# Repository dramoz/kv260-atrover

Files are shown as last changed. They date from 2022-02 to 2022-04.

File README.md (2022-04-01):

# Kria KV260-ATRover
[Adaptive Computing Challenge 2021 report](https://github.com/dramoz/kv260-atrover/blob/main/KV260-atrover.md)

# License(s)

***Copyright (c) 2022 Danilo Ramos***

- Code is licensed under MIT License unless specified to the contrary on the file or subfolder.

- 3D models are licensed under [Attribution-ShareAlike 4.0 International (CC BY-SA 4.0)](https://creativecommons.org/licenses/by-sa/4.0/) unless specified to the contrary on the file(s) or subfolder(s).

- Most models are licensed under [Attribution-NonCommercial-ShareAlike 4.0 International (CC BY-NC-SA 4.0)](https://creativecommons.org/licenses/by-nc-sa/4.0/), **unless specified in the file(s), subfolder(s) or website (please double check)**
  - [3Dmodels/modules/ModulesInfo.md](3Dmodels/modules/ModulesInfo.md)

THE FILES IN THIS REPOSITORY ARE PROVIDED BY THE COPYRIGHT HOLDERS AND CONTRIBUTORS "AS IS" AND ANY EXPRESS OR IMPLIED WARRANTIES, INCLUDING, BUT NOT LIMITED TO, THE IMPLIED WARRANTIES OF MERCHANTABILITY AND FITNESS FOR A PARTICULAR PURPOSE ARE DISCLAIMED. IN NO EVENT SHALL THE COPYRIGHT HOLDER OR CONTRIBUTORS BE LIABLE FOR ANY DIRECT, INDIRECT, INCIDENTAL, SPECIAL, EXEMPLARY, OR CONSEQUENTIAL DAMAGES (INCLUDING, BUT NOT LIMITED TO, PROCUREMENT OF SUBSTITUTE GOODS OR SERVICES; LOSS OF USE, DATA, OR PROFITS; OR BUSINESS INTERRUPTION) HOWEVER CAUSED AND ON ANY THEORY OF LIABILITY, WHETHER IN CONTRACT, STRICT LIABILITY, OR TORT (INCLUDING NEGLIGENCE OR OTHERWISE) ARISING IN ANY WAY OUT OF THE USE OF THIS SOFTWARE, EVEN IF ADVISED OF THE POSSIBILITY OF SUCH DAMAGE.

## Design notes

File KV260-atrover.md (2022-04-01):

# Kria KV260-ATROVER (mini)

***A journey through machine learning and Xilinx Kria KV260 Vision AI Starter Kit***

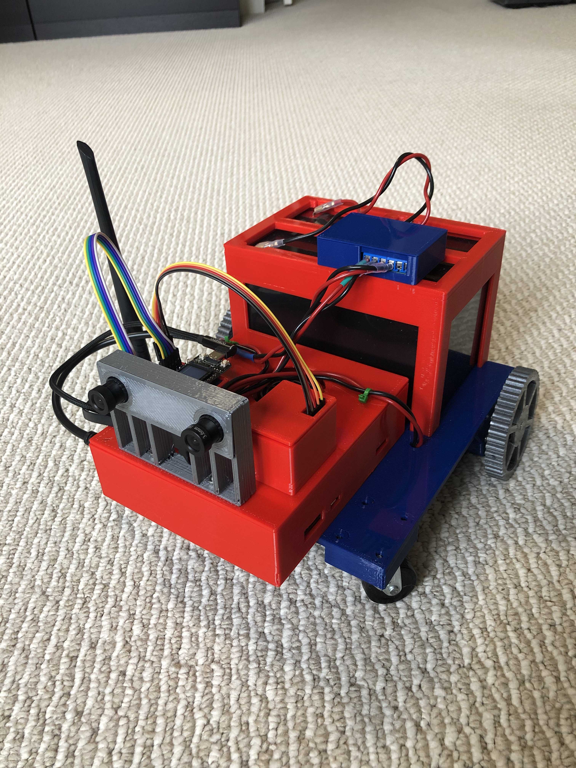
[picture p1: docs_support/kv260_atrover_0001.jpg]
|  |
| :----------------------------------------------------------: |

*Disclaimer:* The following project was done for the [Adaptive Computing Challenge 2021](https://www.hackster.io/contests/xilinxadaptivecomputing2021). Most of the code and 3D models are under [The MIT License | Open Source Initiative](https://opensource.org/licenses/MIT) or  [Attribution-ShareAlike 4.0 International (CC BY-SA 4.0)](https://creativecommons.org/licenses/by-sa/4.0/) unless specified to the contrary. A copy of this document and the corresponding project files are located at the [KV260-ATRover GitHub repository](https://github.com/dramoz/kv260-atrover). As part of the application process, I received a [free Kria KV260 AI Starter Kit + Basic Accessory Pack](https://www.hackster.io/contests/xilinxadaptivecomputing2021/hardware_applications#challengeNav).

⚠ This project uses high DC amperage which can be ☠ -  please use extreme caution.

⚠ All links and references are set to match the tools version used in this project, which most of the time are not the latest. Readers are welcome to go further, as new releases came with significant improvements.

> Vitis-AI v1.4 and v1.4.1 share the same database, and I found that the information available is more complete on v1.4.1

# Introduction

The idea of having a self-driving vehicle platform has been going around my head for a long time now. First, it started with my personal experience with some robot vacuums which became a relation of love and not-that-much hate. With the passing of the years, I have enjoyed the benefits of keeping my floors clean (I suffer a lot from dust allergies), but with the passing of the years, I keep seeing the same problems - which became worst when your family grows and your kids behave like kids.

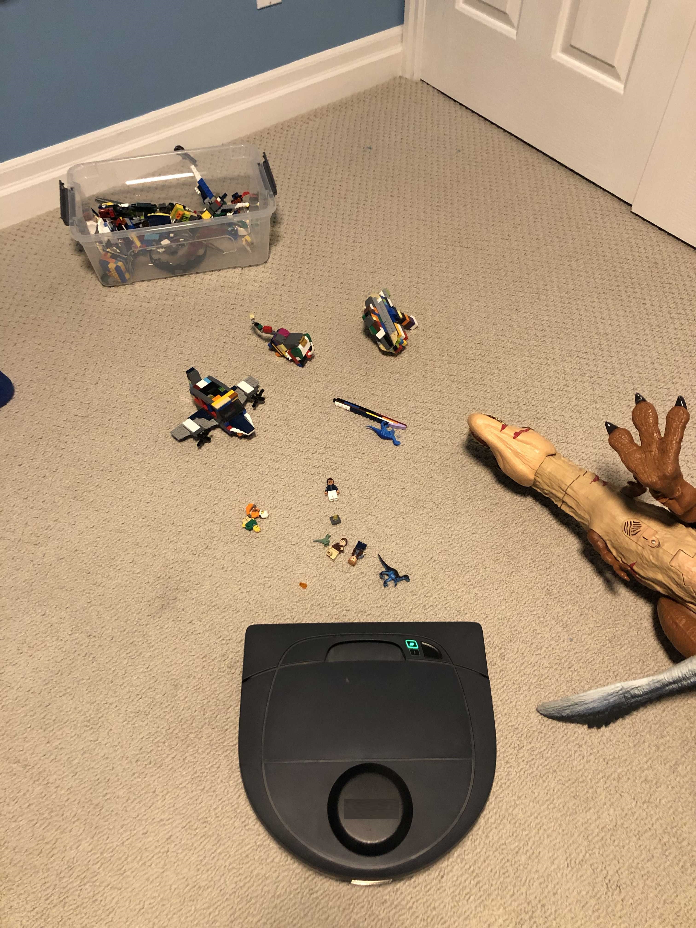
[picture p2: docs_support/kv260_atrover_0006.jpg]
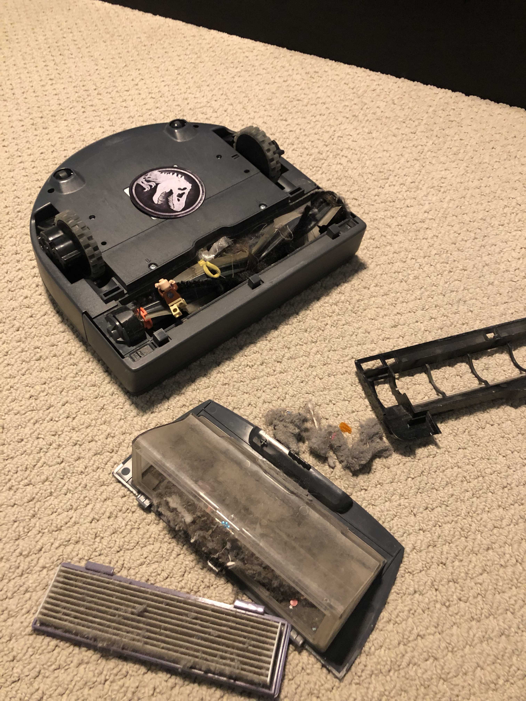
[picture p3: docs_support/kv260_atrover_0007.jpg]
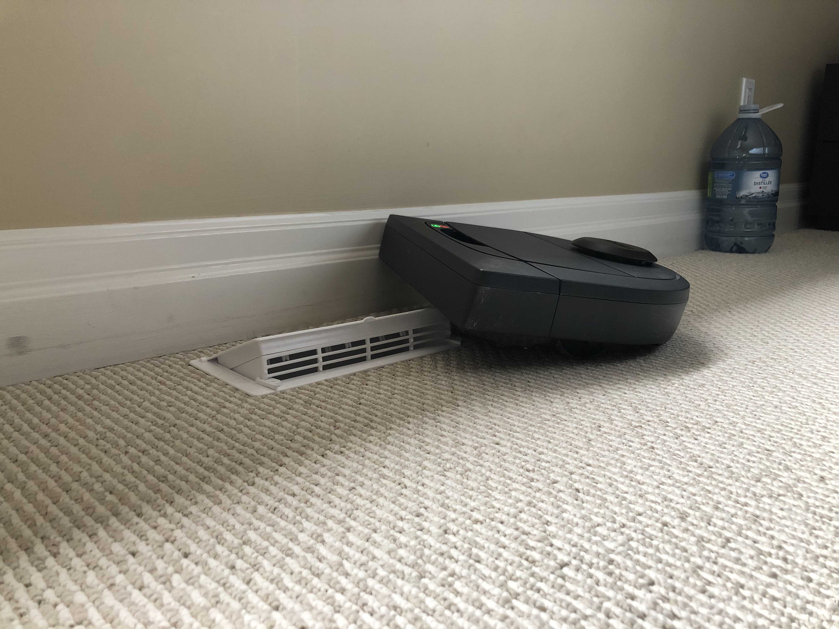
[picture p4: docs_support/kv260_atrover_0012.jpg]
|  |  |  |
| --- | --- | --- |

And then the we moved to a rural house outside Ottawa, and cutting the grass although relaxing, is time-consuming. I started working around a full autonomous acreage lawn mower which I wanted to have an FPGA (just because), when I came across the [Adaptive Computing Challenge 2021](https://www.hackster.io/contests/xilinxadaptivecomputing2021) on [HacksterIO](https://www.hackster.io/) - and that was my [application for free hardware](https://www.hackster.io/contests/xilinxadaptivecomputing2021/hardware_applications/13951). But after starting from almost zero knowledge on both Xilinx Zynq Ultrascale+ and AI/ML (Artificial Intelligence/Machine Learning) I run out of time, plus I live in Canada, so a lawnmower was out of the question during winter.

So I decided to step back, and start with a basic ATRover (AuTonomous Rover) and the KRIA KV260-ATRover  mini version was born - the prototype of an autonomous self-driving mini-rover based on the [Kria KV260 Vision AI Starter Kit](https://www.xilinx.com/products/som/kria/kv260-vision-starter-kit.html) (Zynq Ultrascale+)

My objectives when joining the challenge were:

- Learn about the Xilinx Zynq Ultrascale+ devices
- Go into AI (Artificial Intelligence) and ML (Machine Learning)

## KV260-ATROVER (mini)

The KV260-ATROVER (mini) has the following features:

- Full 3D Printed chassis with OpenSCAD
- KRIA KV260 board (master)
  - AI Object Identification (YOLOv4)
  - OpenCV Stereo Vision for distance estimation (reference)

- TTGO-T1 board (slave)
  - Dual DC motor control

## Motivation

Stereo Vision, DC motor control, route planning, and navigation require a lot of calibration. In the long term, my final goal is to explore and implement a fully autonomous robot with self-learning capabilities, where the required effort for initial calibration is minimized.

As an example, you can watch [OpenCV Python ](https://www.youtube.com/playlist?list=PLLf0llgjmNiZrt5QocH1zq7ih-GdKMgCY)videos from [Clayton Darwin ](https://www.youtube.com/c/ClaytonDarwin)where he does a good explanation of the required process to do triangulation using two cameras and OpenCV. An that is just triangulation, PID motor control, route planning, and context awareness by themself are quite complex, doable but limited, and space-constrained - and this is why and where AI/ML (CNN) keeps growing in many fields.

# Hardware

The ATRover chassis is a custom-made 3D printed model. The design was done in [OpenSCAD](https://openscad.org/). The chassis is modular, so it is possible to reuse for example the KV260 enclosure for future projects. The weight of the assembled ATRover is around 6Kg.

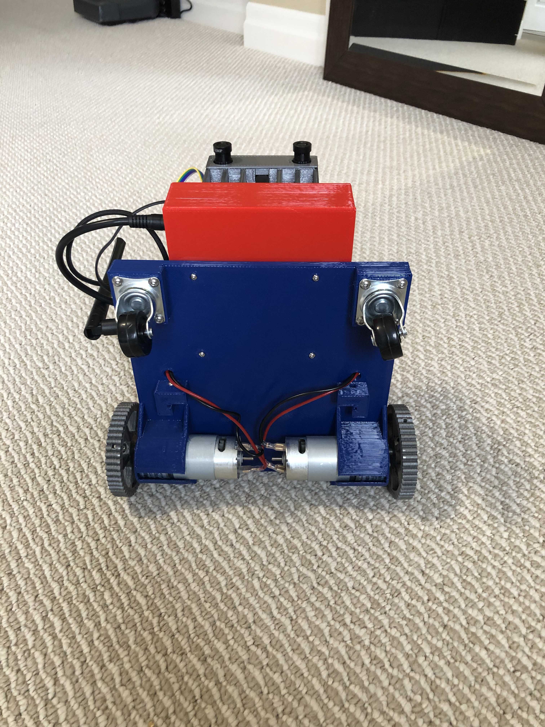
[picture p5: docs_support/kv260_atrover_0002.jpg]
|  |  |
| --- | --- |
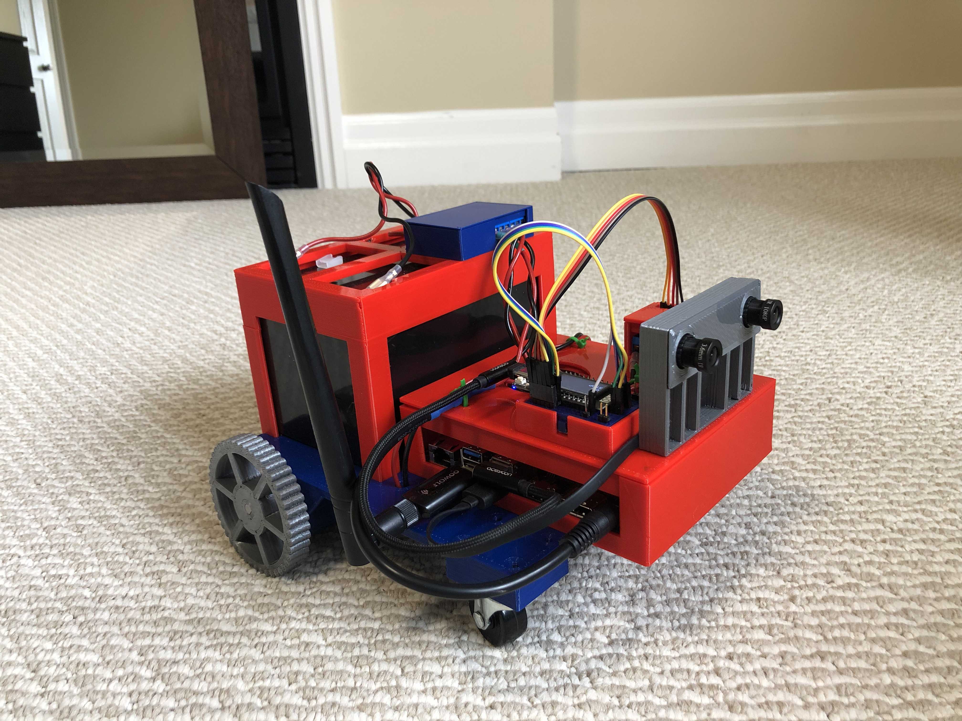
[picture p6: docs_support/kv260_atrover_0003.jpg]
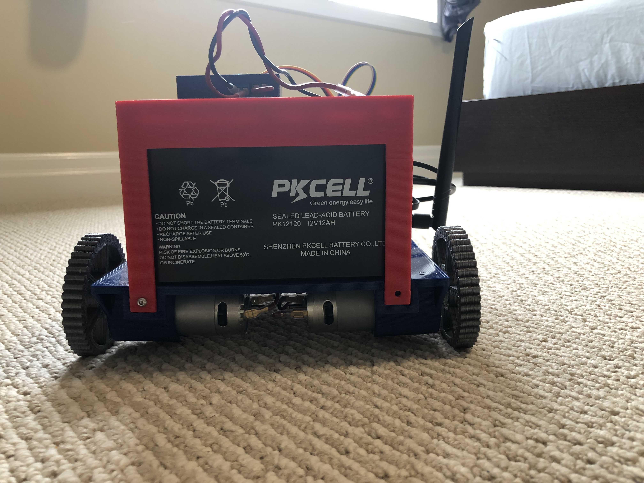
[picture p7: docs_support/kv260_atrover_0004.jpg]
|  |  |

## [Kria KV260 Vision AI Starter Kit](https://www.xilinx.com/products/som/kria/kv260-vision-starter-kit.html)

The hardware selected for this project is the Xilinx KRIA KV260 board, which was awarded as free hardware in this challenge. Another good candidate is the [Avnet - Ultra96-V2 Board](https://www.avnet.com/wps/portal/us/products/new-product-introductions/npi/aes-ultra96-v2/) which has similar characteristics. One advantage of the KRIA Zynq (XCK26) vs the ZU3EG in the Ultra96-V2 is the [VCU (Video Codec Unit)](https://www.xilinx.com/products/intellectual-property/v-vcu.html) which makes it an ideal platform for R&D video applications (live stream)

The KRIA SOM installed in the KV260 Vision AI Starter Kit is a special (non-commercial) SOM, with similar characteristics to the [Kria K26C SOM](https://www.xilinx.com/products/som/kria/k26c-commercial.html). The KV260 has only a single 240-Pin connector and is not certified.

## Stereo Camera

For this project, the [HBVCAM-1780-2](https://www.hbvcamera.com/dual-lens-usb-cameras/1mp-720p-hd-binocular-camera-module.html) binocular camera was selected as it already outputs a dual stereo image synchronized in a single USB port (stream), and it has a decent price.

The camera was tested with https://webcamtests.com/ to validate the manufacturer parameters:

- Max. resolution: 1.84 MP, 30 FPS at 2560×720 (dual image, 2x 1280x720)
- Angle of view: 72 degrees (3.6mm lenses)
- Distance between lenses: 60mm
- Object distance: 30cm ~ $\infty$ (fixed focus - manual adjustable)
- Dual Image Resolution: `640*240 (30fps), 1280*480 (30fps), 2560*720 (25fps)` (validated)
  - single camera: `320*240 (30fps), 640*480(30fps), 1280*720 (30fps)`
- Connection: micro USB2.0
- 2x[OV9732](https://www.ovt.com/products/ov09732-h35a/) Sensors
  - Optical format: 1/4"
  - Array size: 1280*720

| 1MP 720P HD Binocular Camera Module |
| :----------------------------------------------------------: |

As the camera lenses produce some distortion on the capture images, it is necessary to perform a camera calibration as described in [Stereo Vision Camera Calibration in Python with OpenCV](https://youtu.be/yKypaVl6qQo). A modified set of Python scripts used for this project can be found at https://github.com/dramoz/kv260-atrover/tree/main/scripts/camera_calibration_data_gen. The parameters obtained are particular for the module used in this project, and it must be done on a per-module basis.

The scripts are based on [niconielsen32-ComputerVision/stereoVisionCalibration](https://github.com/niconielsen32/ComputerVision/tree/master/stereoVisionCalibration) modified to use one single stereo camera stream plus some personal modifications.

## DC Motors

For the KV260-ATRover the [CHIHAI GM37-550 DC motor ](https://www.aliexpress.com/item/4000808942638.html?pdp_ext_f={"sku_id":"10000008104483462","ship_from":""}&gps-id=pcStoreJustForYou&scm=1007.23125.137358.0&scm_id=1007.23125.137358.0&scm-url=1007.23125.137358.0&pvid=49f50fc1-c29b-4a45-91ae-5cb7468be7b7&spm=a2g0o.store_pc_home.smartJustForYou_718209649.0)with a gear ratio of 50:1 and 12Vdc with a maximum input power of 40W was selected.

> The current DC motors are too powerful for the KV260-ATRover mini. They were selected initially for the lawnmower which has a bigger heavier chassis (higher torque requirement) and larger wheels (reducing the speed of the ATRover and therefore increasing the minimum required PWM duty cycle)

|  |
| :----------------------------------------------------------: |

### DC Motor Driver(s)

For the motor drivers, the [ZK-5AD](https://www.aliexpress.com/item/1005002100401855.html) board was selected. It has two [TA6586](https://www.micros.com.pl/mediaserver/UITA6586_0001.pdf) monolithic IC for driving bi-directional DC motors.

- Working Voltage: DC 3.0V-14V
- Input Signal Voltage: DC 2.2V-6.0V
- Drive Current: 5A
- Standby Current: 10uA
- Working Temperature:-20 to 85 Celsius

| ZK-5AD L298N5A Dual DC Motor Drive Module (1 piece) ⋆ | ZK-5AD L298N5A Dual DC Motor Drive Module (1 piece) |
| :---: | --- |

## [LILYGO® TTGO T-Display ESP32](http://www.lilygo.cn/prod_view.aspx?TypeId=50062&Id=1400&FId=t3:50062:3)

For the DC motor control, the plan was to use the Zynq+ Dual-Core ARM  Cortex-R5 processors with FreeRTOS. The initial test was done with a TTGO T-Display (aka TTGO-T1) board. Although I was planning to use the [PMOD](https://digilent.com/reference/pmod/start) to generate the required PWM signals, after burning two drivers and one TTGO-T1 board I decided to leave it for another day.

You can buy a TTGO-T1 board at [Aliexpress](https://www.aliexpress.com/item/33048962331.html) (the Official [LILYGO store](https://lilygo.he.aliexpress.com/store/2090076?spm=a2g0o.detail.1000061.1.59f8142fz8JkSi)). It is based on the [ESP32 Espresiff](https://www.espressif.com/en/products/socs/esp32) ([Wikipedia](https://en.wikipedia.org/wiki/ESP32])), a 32bit MCU Tensilica Xtensa LX6 with integrated WiFi, Bluetooth, and a lot of peripherals. This is the board I usually use for R&D.

| LILYGO® TTGO T-Display ESP32 WiFi and Bluetooth Module Development Board For Arduino 1.14 Inch LCD |
| ------------------------------------------------------------ |

## USB WiFi dongle

To do some telemetry and get some real-time feedback when testing the system, wireless communication with good throughput and low latency was required. As the KV260 lacks a dedicated wireless communication interface, a USB WiFi dongle was selected for this. For more detailed information on how to install the drivers and set up the device used in this project please refer to [Adding USB-WiFi for the Kria KV260 (Ubuntu 20.04.3).](https://www.hackster.io/dramoz/adding-usb-wifi-for-the-kria-kv260-ubuntu-20-04-3-b5e8ea)

|  |
| :----------------------------------------------------------: |

## Power considerations

As the ATRover is a mobile platform, an appropriate power supply was required. SLA batteries are widely used in robotic applications. A [SLA12V/12Ah](https://www.power-sonic.com/wp-content/uploads/2018/12/Technical-Manual.pdf) battery was selected given the following rough estimates:

- KV-260 power requirements: 36W (4Ah)
- DC Motors: 2x21W (42W, 3.5Ah)

Roughly at full power, the ATRover would require 80W or 6.7Ah. Note that the 12Ah capacity is rated for a 20Hr operation. A constant 3~4A discharge would reduce the capacity to ~9Ah, and give you between 2~3hr. The motors are running at half the capacity or lower speed.

## Other components

To complete assemble an ATRover mini, some other components are required:

- 3D printed chassis
- M3 screws
  - chasis
- Power distribution block
- Power cables ([AWG16](https://www.powerstream.com/Wire_Size.htm))
  - KRIA power cable
  - DC motors
- TTGO-T1 ZK-5AD connector
- micro-USB cable for Stereo Camera
- USB-C cable for TTGO-T1

Please refer to the BOM at the repository for more information.

# Software/Firmware

The journey through the KRIA KV-260 and Xilinx Development Tools was extensive and extenuating. Although I have learned a lot, in the end, with the timeline nearer every day, I have to make a choice and start doing some real deployment.

Given that there was no easy way to install the USB/WiFi drivers or any other driver (like the TTGO-T1 USB-Serial) in the [Petalinux ](https://www.xilinx.com/products/design-tools/embedded-software/petalinux-sdk.htm)flow, I decided to work with Ubuntu. [PYNQ for the KV260 ](https://github.com/Xilinx/Kria-PYNQ)was made available [two months ago.](https://community.element14.com/technologies/fpga-group/f/forum/50595/pynq-now-available-for-the-kria-kv260-vision-ai-starter-kit) Given that scripting is clearer with Python, I decided to switch to PYNQ. Initially, it worked right away without any issues. Running the examples and tutorials is more comfortable and easier to grasp.

## Required tools

- [Kria-PYNQ](https://github.com/Xilinx/Kria-PYNQ)
- [Vitis-AI v1.4.1](https://github.com/Xilinx/Vitis-AI/tree/1.4.1): the DPU-PYNQ uses version 1.4, but using v1.4.1
-  [Visual Code](https://code.visualstudio.com/) + [PlatformIO](https://platformio.org/platformio-ide): the KV260 ATRover uses a TTGO-T1 board to control the DC motors via USB/Serial port. Please follow the instructions on each website to install the tools.

## [Kria PYNQ](https://github.com/Xilinx/Kria-PYNQ)

> [Kria SOMs x Ubuntu x PYNQ](https://pages.xilinx.com/EN-WB-2022-03-22-KriaPYNQUbuntu_LP-Registration.html): nice introductory webinar

The PYNQ framework on the KRIA KV-260 is pretty simple to use.

- It runs on Ubuntu 20.04.04 LTS
  - Easier to install new drivers or tools for development (e.g. USB WiFi dongle, USB/UART drivers)
  - Visual Code SSH + PlatformIO Remote Development
- Faster to test and deploy new ideas
  - Python + Jupyter-lab
  - DPU ready overlay (B4096)
- Easy to install and error prune
- Remote access with remote graphics applications (`ssh -X` )

But there are some "*drawbacks*":

- Cannot load multiple overlays
  - e.g. if you need the DPU but at the same time some video pre-processing you are out of luck, but of course you can develop your own overlays
- Performance: in theory, as you are running over Python you will suffer from latency and throughput. 
  - I have not test it, but I will do in the future. Nevertheless, for R&D and testing it is good enough.

### PYNQ install

> At the moment, PYNQ - KRIA installation is *"broken"* [Unable to install PYNQ #9](https://github.com/Xilinx/Kria-PYNQ/issues/9)
> **It is possible to get PYNQ with Xilinx Dev. working by skipping the initial:**
>
>    `sudo apt update; sudo apt upgrade`
>
> and do it only at the end!
>
> *Currently Canonical and PYNQ are working on a new release that will address this issue.*

To install, just follow the instructions on the official GitHub repository https://github.com/Xilinx/Kria-PYNQ, which can be summarized as:

- Download the [Ubuntu Desktop 20.04.4 LTS for Xilinx Kria KV260](https://ubuntu.com/download/xilinx) ([direct download link](https://people.canonical.com/~platform/images/xilinx/kria/iot-kria-classic-desktop-2004-x03-20211110-98.img.xz))

- Burn the image on an SD card

  - Load the SC card and power up the board

- Logging (GUI or Terminal, GUI experience is recommended)

  - **username**: ubuntu

  - **password**: ubuntu (OS will prompt to set a new password)

    after the first password input, key the current password again - **ubuntu** and enter a new password (twice)

  - Skip Ubuntu/GNOME settings (I did not see a need to do a full Ubuntu configuration at the moment)
  - Optional Settings (GUI: right click)
    - Appearance: move and resize the toolbar
    - Power.Blank_Screen: Never

> After initial configuration and having a valid IP, I prefer to do most of the configuration using ssh
>
> `ssh ubuntu@xxx.xxx.xxx.xxx`

- On a terminal window

  ```bash
  # Setup git credentials
  git config --global user.email "yout@email"
  git config --global user.name "Your Name"
  ```

  > **Skip next step until new Ubuntu/PYNQ release**

  ```bash
  sudo apt update -y; sudo apt upgrade -y; sudo apt autoremove -y;
  sudo reboot
  ```

> Note: As soon as you power up the KRIA KV260, after login - the OS will start an update status query, which will lock some process causing the next steps to lock for a couple of minutes.
>
> Some info related to this issue can be read here https://xilinx-wiki.atlassian.net/wiki/spaces/A/pages/2037317633/Getting+Started+with+Certified+Ubuntu+20.04+LTS+for+Xilinx+Devices

| SOM Kria KV260 connection animation |
| :----------------------------------------------------------: |

> The IAS camera module is not required!!!

- Setup Xilinx Development Environment

  ```bash
  # if GUI, open a new terminal session (right click)
  cd ~
  sudo snap install xlnx-config --classic
  xlnx-config.sysinit
  # -> [Y] when asked
  ```

- Install PYNQ

  ```bash
  git clone https://github.com/Xilinx/Kria-PYNQ.git
  cd Kria-PYNQ/
  sudo bash install.sh
  ```

- Testing PYNQ
  - Run the [DPU resnet50](http://kria:9090/lab/workspaces/auto-e/tree/pynq-dpu/dpu_resnet50.ipynb) to validate the DPU-PYNQ installation

```bash
# Open in your local desktop webbrowser:
kria:9090/lab
# !try some examples
# if the kria:9090/lab is not working, try the IP directly
# To get the IP type the `ip a` command and look for eth0:...
ip a
```

> 3: eth0: <BROADCAST,MULTICAST,UP,LOWER_UP> mtu 1500 qdisc mq state UP group default qlen 1000
>     link/ether 00:0a:35:00:22:01 brd ff:ff:ff:ff:ff:ff
>     inet **192.168.0.134**/24 brd 192.168.0.255 scope global dynamic noprefixroute eth0
>        valid_lft 7191sec preferred_lft 7191sec
>     inet6 fe80::1fe:9c9e:1eaf:a932/64 scope link noprefixroute 
>        valid_lft forever preferred_lft forever

## Vitis-AI (v1.4.1)

> Vitis-AI requires around 100GB of hard drive space

As the current Vitis-AI version is 2.0, but DPU-PYNQ requires v1.4.1, please follow the next steps to install the proper tool version. Vitis-AI is installed and run in your local machine (Ubuntu)

**Installation steps**

- [Install docker](https://docs.docker.com/engine/install/)

  ```bash
  # Prerequisites
  sudo apt install -y ca-certificates curl gnupg lsb-release
  curl -fsSL https://download.docker.com/linux/ubuntu/gpg | sudo gpg --dearmor -o /usr/share/keyrings/docker-archive-keyring.gpg
  echo "deb [arch=$(dpkg --print-architecture) signed-by=/usr/share/keyrings/docker-archive-keyring.gpg] https://download.docker.com/linux/ubuntu $(lsb_release -cs) stable" | sudo tee /etc/apt/sources.list.d/docker.list > /dev/null
  
  # Docker engine
  sudo apt install -y docker-ce docker-ce-cli containerd.io
  
  # Setup group access
  sudo groupadd docker
  sudo usermod -aG docker $USER
  su $USER
  
  # Test installation
  sudo docker run hello-world
  ```

- Install Vitis-AI

  ```bash
  mkdir -p ~/repos
  cd repos
  git clone --recurse-submodules https://github.com/Xilinx/Vitis-AI
  cd Vitis-AI
  git checkout 1.4
  ```

- Get [Docker image](https://github.com/Xilinx/Vitis-AI/blob/1.4/docs/quick-start/install/install_docker/load_run_docker.md):

  ```bash
  docker pull xilinx/vitis-ai-cpu:1.4.916
  ```

  Alternatively, you can build the docker image with:

  ```bash
  cd setup/docker
  ./docker_build_cpu.sh
  ```

- Launch Vitis-AI

  ```bash
  ./docker_run.sh xilinx/vitis-ai-cpu:1.4.916
  ```

## Additional Drivers & Ubuntu configuration

### Ubuntu packages

```bash
sudo apt install -y dkms net-tools build-essential
```

### USB WiFi

```bash
mkdir repos; cd repos
git clone https://github.com/morrownr/88x2bu-20210702
cd 88x2bu-20210702
sudo ARCH=arm64 ./install-driver.sh
```

> Do you want to edit the driver options file now? [y/N] **n**
> Do you want to reboot now? (recommended) [y/N] **n**

```bash
# TTGO-T1 UART/USB drivers
cd ~/repos
git clone https://github.com/WCHSoftGroup/ch343ser_linux.git
cd ch343ser_linux/driver
make ARCH=arm64
sudo make install
sudo reboot
```

### WiFi configuration

The easiest way to configure the WiFi is through GNOME. After login, click on the down icon near the power button ⏻▼ and select your network. This connection will be preserved after shutdown without the need of login.

Alternatively you can set it on the command line. Currently I do not know how to make a connection permanently (aka WiFi connection without login), so the GUI method is recommended.

### Final steps

```bash
sudo apt update -y; sudo apt upgrade -y; sudo apt autoremove -y; sudo reboot
```

### ***Optional packages***

```bash
sudo apt install -y graphviz gtkwave tree meld
```

### Optional Python Virtualenv Wrapper

> ⚠ PYNQ has its own `virtualenv` setup, I did not test creating a new one and I do not know if there would be any side effect on doing so

```bash
cd ~
pip3 install virtualenv virtualenvwrapper
```

With your favorite editor append the following lines to `.bashrc`

> \# virtualenv and virtualenvwrapper
> export WORKON_HOME=\${HOME}/.virtualenvs
> export VIRTUALENVWRAPPER_PYTHON=/usr/bin/python3
> export VIRTUALENVWRAPPER_VIRTUALENV=\$HOME/.local/bin/virtualenv
> source \$HOME/.local/bin/virtualenvwrapper.sh

💡In the [KV260-ATRover GitHub repository](https://github.com/dramoz/kv260-atrover) I have provided a set of `.bash` configuration scripts that include some extra setup for Ubuntu command line terminals including the above `virtualenv and virtualwrapper` setup. 

They will transform the command line prompt from

|  |
| ------------------------------------------------------------ |

to

|  |
| :----------------------------------------------------------- |

You can install them next after cloning the project repository.

# Project files

```bash
cd ~
mkdir dev
cd dev
git clone https://github.com/dramoz/kv260-atrover
```

NOTE: you can use [Visual Code remotely with SSH](https://code.visualstudio.com/docs/remote/ssh).

> Click ≶ icon on the bottom left corner and create a new connection.

Create a symbolic link to the repository so it is accessible from jupyter-lab

```bash
cd $PYNQ_JUPYTER_NOTEBOOKS
ln -s $HOME/dev/kv260-atrover/ kv260-atrover
```

Copy the `.bashrc` configuration (optional)

```bash
cp -fv ~/dev/kv260-atrover/scripts/.bash* ~/
source ~/.bashrc
```

Finally, install the required python dependencies:

```bash
pip install -r ~/dev/kv260-atrover/scripts/requirements.txt
```

### TTGO-T1 firmware

The TTGO-T1 code is a simple four-channel PWM generator connected to the ZK-5AD motor driver. It communicates to the KV260 board with a USB/Serial port. The KV260 application send the following commands as requried:

- `*m###, m in [f, b, r, l, s]`

  - f: forward
  - b: backward
  - r: turn right
  - l: turn left
  - s: stop
  - ###: desired step value, between `min/max_step` range (number string must be 3 numeric characters)

  example: `*f064`

- `!xxxx`: emergency stop (any four *xxxx* characters)

The following parameters can be configured (required to flash a new firmware into the board):

- `min/max speed`: in steps to control the PWM duty cycle
- `PWM frequency` and `PWM resolution`
- acceleration: by means of `speed_step` and update rate (`accel_step_ms`)

The default parameters were set on a trial an error basis as:

- `min_step`: 32, `max_step`: 128
- [PWM frequency](https://electronics.stackexchange.com/questions/242293/is-there-an-ideal-pwm-frequency-for-dc-brush-motors/): 8Hz
- `speed_step`: 8, `accel_step_ms`: 200

The firmware of the TTGO-T1 board was developed using Visual Code PlatformIO. After installing Visual Code + PlatformIO, clone the project repository on a local machine and add the [ttgo-atrover-motor-control](https://github.com/dramoz/kv260-atrover/tree/main/ttgo-atrover-motor_control) project to PlatformIO. Connect the board to an available USB serial port, compile (✓) and flash (➔) the board by clicking on the icons located at the bottom toolbar in VS code.

💡It is possible to program the TTGO-T1 board directly from the KRIA KV-260 with [PlatformIO Remote Development](https://docs.platformio.org/en/stable/plus/pio-remote.html) tools.

> A free PlatformIO account is required for remote development.

On your local machine

- Open Visual Studio Code

  ```bash
  # CTRL+SHIFT+P
  # Start typing Platf...
  # -> Click PlatformIO: New Terminal
  pio account register
  pio account login
  ```

On the KV260

- Install

  ```bash
  python3 -c "$(curl -fsSL https://raw.githubusercontent.com/platformio/platformio/master/scripts/get-platformio.py)"
  ```

- Update `.bashrc` (already present if `.bashrc` was updated from the repository)

  ```bash
  export PATH=$PATH:$HOME/.platformio/penv/bin
  ```

- Install the [platformio-udev-rules](https://docs.platformio.org/en/stable/faq.html#platformio-udev-rules)

  ```bash
  curl -fsSL https://raw.githubusercontent.com/platformio/platformio-core/master/scripts/99-platformio-udev.rules | sudo tee /etc/udev/rules.d/99-platformio-udev.rules
  sudo service udev restart
  sudo usermod -a -G dialout $USER
  sudo usermod -a -G plugdev $USER
  ```

- Login and start the remote agent

  ```bash
  pio account login
  pio remote agent start
  ```

  > The first call to `pio remote agent start` will require some time while the required packages and dependencies are installed

Local machine remote programming

- On a PlatformIO terminal in VS code

  > Check that the terminal current path is at `~/dev/kv260-atrover/ttgo-atrover-motor_control/`

- Check KV260 remote agent

  ```bash
  #pio account login (if required)
  pio remote agent list
  ```

  > kria
  > \----
  > ID: 827c99104301d4120ea475faee3371703eddc89f
  > Started: 2022-03-27 00:28:45

  ```bash
  pio remote run -t upload --upload-port /dev/ttyCH343USB0
  ```

PlatformIO Remote Development is a useful remote programing tool, as if required for example to change the PWM frequency for the DC motors control, we can reprogram the TTGO-T1 without the need of unplugging it from the KV260 board.

# Basic system tests

All the scripts are done in Python using Visual Studio code. Although JupyterLab was nice for the initial R&D, it is faster to run some OpenCV like `imshow()` outside the Jupyter environment, with `ssh -X`.

## TTGO-T1 and DC motors

```bash
ssh ubuntu@kria_ip
screen /dev/ttyCH343USB0 115200
```

Press the TTGO-T1 reset button, a message similar to this would appear

> rst:0x1 (POWERON_RESET),boot:0x13 (SPI_FAST_FLASH_BOOT)
> configsip: 0, SPIWP:0xee
> clk_drv:0x00,q_drv:0x00,d_drv:0x00,cs0_drv:0x00,hd_drv:0x00,wp_drv:0x00
> mode:DIO, clock div:2
> load:0x3fff0018,len:4
> load:0x3fff001c,len:1216
> ho 0 tail 12 room 4
> load:0x40078000,len:10944
> load:0x40080400,len:6360
> entry 0x400806b4
> **?TTGO**

Run some commands: `*f064`, `*b128`, `*s0000`, `*l128`, `!0000` ...

When done, disconnect screen to free serial port

> `ctrl+a, k`
>
> Really kill this window [y/n] `y`
>
> [screen is terminating]
> ubuntu@kria:~/$

## Stereo camera test

To run a simple test on the stereo camera:

```bash
ssh -X ubuntu@kria_ip
cd ~/dev/kv260-atrover/scripts/
python camera_test.py
```

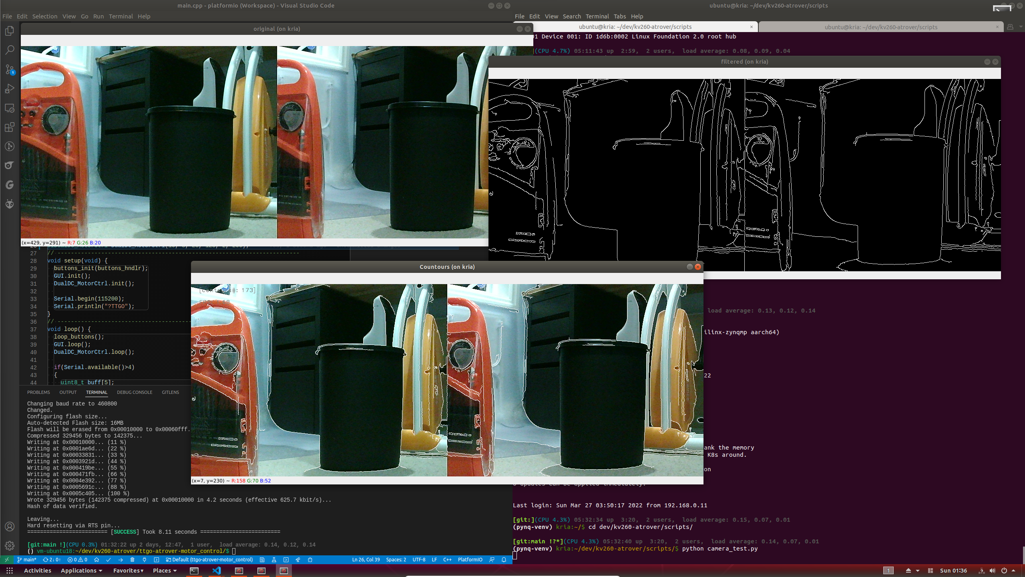
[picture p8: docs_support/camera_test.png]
|  |
| :----------------------------------------------------------: |

The triangulation test is based on [niconielsen32-ComputerVision/StereoVisionDepthEstimation/](https://github.com/niconielsen32/ComputerVision/tree/master/StereoVisionDepthEstimation) modified to use one single stereo camera stream.

> The triangulation test is loading the calibration matrices and applying the OpenCV remap on both frames. As can be seen in the pictures, the black regions surrounding the frames are a side effect of remapping the frames. It is also noticeable the difference between both camera module lenses.

```bash
ssh -X ubuntu@kria_ip
~/dev/kv260-atrover/scripts/triangulation_example/
python camera_test.py
python stereoVision.py
```

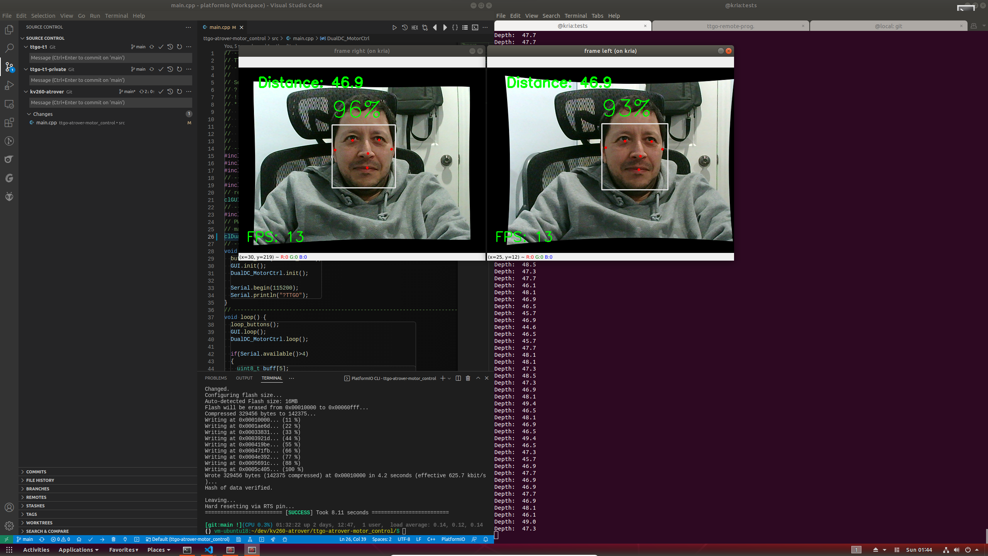
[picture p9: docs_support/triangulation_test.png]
|  |
| :----------------------------------------------------------: |

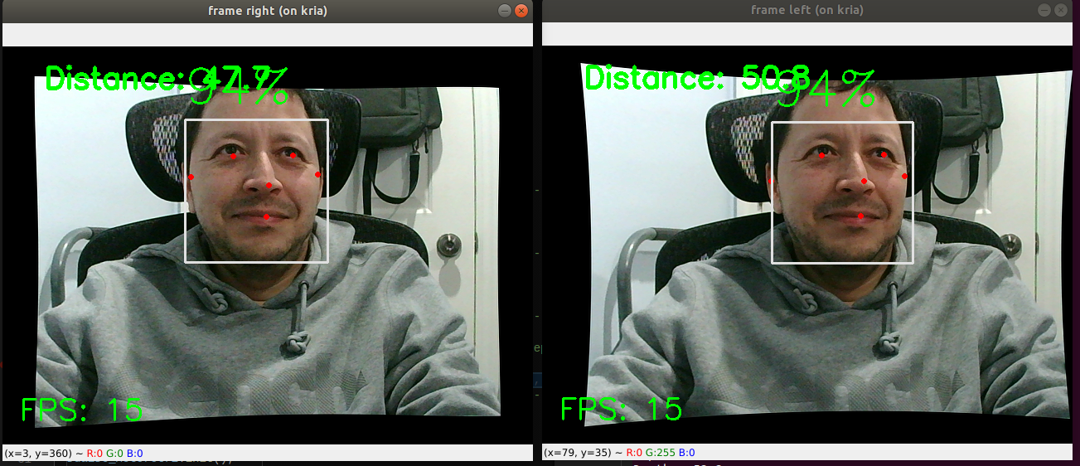
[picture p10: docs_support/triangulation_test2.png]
|  |
| ------------------------------------------------------------ |

>  ☝ At the moment, the triangulation demo is exiting with a `Segmentation fault (core dumped)` error which I did not have time to investigate further at the moment of writing this project.

## **Movement Test**

A simple script to validate the communication between the KV260 board and the TTGO while testing the motors was done.

VIDEO: https://youtu.be/WgYcuWozWEg

# Selecting the model(s)

Xilinx provides with the Vitis-AI framework a set of pre-trained NN models that can be used as a starting point. It is referenced as [Vitis-AI AI-Model-Zoo](https://github.com/Xilinx/Vitis-AI/tree/master/models/AI-Model-Zoo). The models are deployed on the FPGA on the DPU IP. As the DPU comes in different flavors, please note that if the model is not available for the current DPU model, extra steps are required with Vitis-AI framework to deploy the solution properly.

- The KRIA KV260 examples run on Petalinux and use a [DPU B3136](https://xilinx.github.io/kria-apps-docs/2020.2/build/html/docs/smartcamera/docs/hw_arch_accel.html), with Xilinx tools 2021.1
- The PYNQ has an overlay [DPU-PYNQ](https://github.com/Xilinx/DPU-PYNQ) with a [DPU B4096](https://github.com/Xilinx/DPU-PYNQ/blob/master/boards/KV260/dpu_conf.vh), and uses Vitis-AI 1.4.0

When selecting the model for this project, one useful metric available at the AI Model Zoo worth mentioning is the [Performance of Kria KV260 SOM](https://github.com/Xilinx/Vitis-AI/tree/v1.4.1/models/AI-Model-Zoo#performance-on-kria-kv260-som). It summarizes the KV260 latency and throughput of the available model.

CNN's are available in different topologies, which basically define the application target. Furthermore, each model can be trained using different data sets ([ImageNet](https://www.image-net.org/), [COCO](https://cocodataset.org/), [CityScapes](https://www.cityscapes-dataset.com/), [SYNTHIA](http://synthia-dataset.net/) among others)

From the different topologies available in the AI Model Zoo, the following were selected to do some R&D:

- [YOLO](https://towardsdatascience.com/yolo-you-only-look-once-real-time-object-detection-explained-492dc9230006): (You Only Look Once) object detection and classification
- [SSD](https://towardsdatascience.com/understanding-ssd-multibox-real-time-object-detection-in-deep-learning-495ef744fab): (Single Shot MultiBox Detector) object detection.
- [FADnet](https://arxiv.org/abs/2003.10758) ([GitHub repository](https://github.com/HKBU-HPML/FADNet)): disparity estimation

## [**Downloading a model**](https://github.com/Xilinx/Vitis-AI/tree/1.4/models/AI-Model-Zoo#automated-download-script)

> Models are downloaded to the local machine where Vitis-AI was installed and later transfer with [`spc`](https://acloudguru.com/blog/engineering/ssh-and-scp-howto-tips-tricks) to the ATRover.

> To validate the Kria-PYNQ framework running on the KV-260, the resnet50 model was also downloaded. 

To download the models, for each model do:

```bash
cd ~/repos/Vitis-AI/models/AI-Model-Zoo/

# -----------------------------------------------------------
# Caffe resnet50
# file: resnet50-zcu102_zcu104_kv260-r1.4.0.tar.gz
python downloader.py
> input: `cf resnet50`
2: ['type', 'xmodel']['board', 'zcu102 & zcu104 & kv260']
> input num: `2`
done
# -----------------------------------------------------------
# Darknet YOLOV4
# file: yolov4_leaky_spp_m-zcu102_zcu104_kv260-r1.4.0.tar.gz
python downloader.py
> input:dk yolov4
1 : dk_yolov4_coco_416_416_60.1G_1.4
> input num:1
2:  ['type', 'xmodel']['board', 'zcu102 & zcu104 & kv260']
> input num:2
done
# -----------------------------------------------------------
# PyTorch FADnet
# file: FADNet_2_pt-zcu102_zcu104_kv260-r1.4.0.tar.gz
python downloader.py
> input:pt fadnet
4:  ['type', 'xmodel']['board', 'zcu102 & zcu104 & kv260']
> input num:4
done
# -----------------------------------------------------------
# TensorFlow SSD
# file:
python downloader.py 
> input:tf ssd
4 : tf_ssdresnet50v1_fpn_coco_640_640_178.4G_1.4
> input num:4
2:  ['type', 'xmodel']['board', 'zcu102 & zcu104 & kv260']
> input num:2
done
# ------------------------------------------------------------------------------
# ------------------------------------------------------------------------------
# Models are downloaded as *tar.gz files
du -h *.gz
106M	FADNet_2_pt-zcu102_zcu104_kv260-r1.4.0.tar.gz
18M	resnet50-zcu102_zcu104_kv260-r1.4.0.tar.gz
45M	yolov4_leaky_spp_m-zcu102_zcu104_kv260-r1.4.0.tar.gz

# transfer them to the KV260 SDcard with
scp *.gz ubuntu@192.168.0.198:/home/ubuntu/dev/kv260-atrover/scripts/models

# Connect to the board and untar the files
ssh -X ubuntu@kria_ip
cd ~/dev/kv260-atrover/scripts/models/
for f in ../*.gz; do tar -xvzf "$f"; done
```

>FADNet_2_pt/
>FADNet_2_pt/FADNet_2_pt.xmodel
>FADNet_2_pt/md5sum.txt
>resnet50/
>resnet50/resnet50.prototxt
>resnet50/resnet50.xmodel
>resnet50/md5sum.txt
>yolov4_leaky_spp_m/
>yolov4_leaky_spp_m/yolov4_leaky_spp_m.prototxt
>yolov4_leaky_spp_m/yolov4_leaky_spp_m.xmodel
>yolov4_leaky_spp_m/md5sum.txt

The `*.xmodel` files would be the models to load into the DPU.

## Running the scripts

> Each models requires a pre-process to the input frames and a post-process of the output different in each case. The information can be gather from the Vitis-AI examples, and the Board/GPU models that can be downloaded using the same previous steps (`python downloads.py`) and selecting the board/GPU option
>
> `1:  ['type', 'float & quantized']['board', 'GPU']`
>
> The downloaded files are `.zip` type.
>
> ```bash
> du -h *.zip
> 208M	cf_resnet50_imagenet_224_224_7.7G_1.4.zip
> 529M	dk_yolov4_coco_416_416_60.1G_1.4.zip
> 1.2G	pt_fadnet_sceneflow_576_960_359G_1.4.zip
> ```
>
> The preprocess information is located in the `readme.md` file in each case.
>
> The postprocess depends on each CNN output vector format.

 Test scripts to run each model are located in the repository under the scripts directory.

## Improving the model(s)

Vitis-AI is the tool required to tailor the neural network model to project particular needs. As realized by running some tests, it would be necessary to re-train the current CNN models.

- A suitable dataset: although there are some indoor datasets, most are at higher levels.
- Gathering a dataset is time consuming, and resources hungry.

# Main Application

***Moving out of PYNQ***

Unfortunately, during the final steps of writing this report, it was not possible to run the YOLOv4 in PYNQ and perform some final tests. A temporal solution was provided by Xilinx support. However, it was not compatible with my Python scripts or disabled the possibility of WiFi and UART/Serial interfaces. And, I ran out of time. Therefore (and sadly), it was not possible to present more videos or capture better examples of the working project.

The main application gathers the identified objects from YOLOv4 or SSD on both video channels, and by using the triangulation OpenCV algorithm it provides a rough estimate of the distance from the ATRover to the object. If a dog is identified by the ATRover, it will try to preserve the distance and follow or move back from it.

# Final Remarks

This experience was a short/long journey with the KRIA KV-260. Initially, I was contemplating getting an Ultra96-V2 as it seemed better on paper for this type of project, but the free hardware option was the KV-260.

In retrospect, my gut feeling was 50/50. On one side, I think the Ultra96-V2 is "better" suited for the ATRover with its smaller form factor, ready WiFi, and more I/O ports available out of the box. On the other side, the Kria KV-260 has more USB Ports, extra camera ports, doubles the DDR-RAM and is capable of video streaming with its integrated VCU (Video Codec Unit) - features that make it ideal for R&D, which is the main idea behind the KV-260 Starter kit.

As a plus, there is no need to configure any jumpers to select the boot target, and the capability of dynamic loading overlays is key. Finally, in my case, getting Ubuntu out-of-the-shelf-ready and working without any issues is awesome.

A set of unfortunate events in the last couple of weeks played against the remaining time for the [Adaptive Computing Challenge 2021,](https://www.hackster.io/contests/xilinxadaptivecomputing2021) when things were finally getting interesting.

But it was worth the journey, I came from almost zero AI/ML knowledge and Vitis/Zynq+ to be able to deploy some CNN on a small vehicle platform and make it move around while identifying some objects.

The final activities to have a proper closure of the first ATRover phase that is not done yet given the timing left before submitting the project are:

- BOM: improve the bill of materials with a guide on how to assemble the whole project
- Chassis 3D print: the 3D models are available as OpenSCAD files, but they were fine-tuned to my printer (Ender3 modified to print 2.85mm)
- TTGO-T1 UART drivers installation on the KRIA KV-260 Ubuntu desktop OS: only a short explanation was given in this document.
- DC motor characterization + improve DC motor control: the current scripts do not have any proper motor control (e.g. PID) and there is no proper motor parameters characterization. Also, the current motor setup is generating too much vibration while running at medium speed.
- Provide in the future more videos of the implemented application.

There will be completed later on a more calm sea, and are not part of this deliverable. Finally, the repo is tagged to preserve the status of the project to comply with the challenge deadline.

# Future work

- **Proper Overlay Pipeline**

  As mentioned earlier, the available architecture for the Kria-PYNQ does not allow to perform video pre-processing while using a DPU. The next step would be to develop a PYNQ overlay more suitable for the KV260-ATRover setup. The overlay should also include a proper video stream generation using the video codec capabilities of the KRIA SOM.

- **Training Dataset**

  From what I found, most current datasets pictures are up to high, and the world is shown from a completely different perspective as compared to an almost floor level ATRover view. Now that the ATRover has some limited mobility, it will be possible to gather new training images to improve the CNN training.

- **DC motors downgrade**

  The current DC motors are too powerful for the KV260-ATRover mini. They were selected initially for the lawnmower which has a bigger heavier chassis (higher torque requirement) and larger wheels (reducing the speed of the ATRover and therefore increasing the minimum required PWM duty cycle)

- **More sensors**

  Additional sensors are planned (and required) to improve the ATRover control:

  - 9-DOF: 3-axis accelerometer and 3-axis gyroscope

  - Ultrasound distance measurement

  - Additional cameras for mapping

  - Cliff sensor

- **Chassis upgrade**

  - Lower the camera position or update the lens to wide angle to capture nearer objects

  - Battery compartment for easy battery replacement.

- **R&D other CNN topologies**
  - Multitask CNN look like an ideal solution for path control and planning including DC motor control.
  - Single CNN dual camera SSD/YOLO with distance estimation as output
  - Self-learning/self-calibration CNN for stereovision camera

- **Explore [ROS2](https://docs.ros.org/en/foxy/index.html)**
- **Web Interface**
  - Although JupyterLab is nice for some work, a minimalistic web interface would be a nice feature to have
- **From PYNQ to C++**
  - After the final drawbacks, I have decided to move to C++ from Python. Although everything looks prettier on Python, an increase in performance should be expected, plus almost everything in the Vitis-AI is done in C++.

# Future Projects

While learning about the Kria KV-260 a couple of projects came to my mind:

- *Where is my dog?* I am on a rural area and occasionally I let my dog out. As he is a small breed I am always worried about him, and a solution like Alexa "show me cam##" does not satisfices my needs. I already got new IP cameras with RTSP and will begin to do some test early summer.
- *Monitor my-Kids free-time*. I work from home, which is great, but for a couple of hours while I am working, my kids are supposed to do the homework - which usually does not work as expected. There should be an easier way to monitor and time screen-time.

Finally, I will try to write some starting tutorials on deploying AI/ML on the Xilinx - MPSoCs, while following the contest forums it was clear that I was not the only one - and I should have asked more questions rather than trying to solve all by myself (but I think that's how I learn more)

# Acknowledgments

I want to tank the HacksterIO community for sharing, answering, and asking questions. HacksterIO and Xilinx staff for the effort and time into promoting these challenges and activities - and answering questions. I found them a great way to improve my know-how.

Last but not the least, my wife and my kids for supporting and not letting me quit, for understanding my occasional absences (or more often coming late to dinner), and for helping with the chores (the ones I was supposed to do)

As always, comments are most welcome.

# References & Links

| Title | Remarks | URL |
| --- | --- | --- |
| KV260-ATRover GitHub repository | This project repository | https://github.com/dramoz/kv260-atrover |

**Tutorials**

| Title | Remarks | URL |
| --- | --- | --- |
| Stereo Vision Camera Calibration | | https://youtu.be/yKypaVl6qQo |
| Camera Calibration using OpenCV  | | https://learnopencv.com/camera-calibration-using-opencv/ |

**Blogs**

| Title | Remarks | URL |
| --- | --- | --- |
| Learn OpenCV | Stereo Vision Tutorials | https://learnopencv.com/author/kaustubh-sadekar/ |

**Xilinx**

| Title | Remarks | URL |
| --- | --- | --- |
| Kria-PYNQ | - | https://github.com/Xilinx/Kria-PYNQ |
| DPU on PYNQ | - | https://github.com/Xilinx/DPU-PYNQ |
| VART | [C++ APIs](https://docs.xilinx.com/r/1.4.1-English/ug1414-vitis-ai/C-APIs)<br />[Python APIs](https://docs.xilinx.com/r/1.4.1-English/ug1414-vitis-ai/Python-APIs) | https://docs.xilinx.com/r/1.4.1-English/ug1414-vitis-ai/VART-Programming-APIs |
| XIR | [Xilinx Intermediate Representation](https://docs.xilinx.com/r/en-US/ug1414-vitis-ai/Compiling-with-an-XIR-based-Toolchain)<br />graph-based intermediate representation of AI algorithms | https://github.com/Xilinx/Vitis-AI/tree/master/tools/Vitis-AI-Runtime/VART/xir |
| DNNDK | Deep Neural Network Development Kit User Guide | https://docs.xilinx.com/v/u/1.6-English/ug1327-dnndk-user-guide |
| Vitis-AI | User Guide | https://docs.xilinx.com/r/1.4-English/ug1414-vitis-ai/Revision-History |
| Vitis-AI Library | User Guide | https://docs.xilinx.com/r/1.4-English/ug1354-xilinx-ai-sdk/Revision-History |
| Vitis-AI GitHub  | [AI-Model Zoo](https://github.com/Xilinx/Vitis-AI/tree/1.4.1/models/AI-Model-Zoo) | https://github.com/Xilinx/Vitis-AI/tree/1.4.1/ |
| DPU YOLOv3 | Old DPU-PYNQ Vitis AI 1.2 YOLOv3 notebook | https://github.com/Xilinx/DPU-PYNQ/blob/v1.2.0/pynq_dpu/edge/notebooks/dpu_yolo_v3.ipynb |

> ⚠ A lot of time was wasted while looking at the wrong Vitis AI User Guide (UG1414) version [v1.4](https://docs.xilinx.com/r/1.4-English/ug1414-vitis-ai/) which was incorrect, the [v1.4.1](https://docs.xilinx.com/r/1.4.1-English/ug1414-vitis-ai/) does contains the required VART API information required to deploy with Vitis AI-1.4

**Wiki**

| Title | Remarks | URL |
| --- | --- | --- |
| CNN Tensor Shape (aka .dims) | Tensors are in the form NHWC (batchsize, height,width,channels) | https://deeplizard.com/learn/video/k6ZF1TSniYk |
| YOLO output | YOLO output data post-processing | https://towardsdatascience.com/yolo2-walkthrough-with-examples-e40452ca265f |
| YOLO + OpenCV | YOLO object detection with OpenCV | https://pyimagesearch.com/2018/11/12/yolo-object-detection-with-opencv/ |
| SSD + Keras | Implementing Single Shot Detector (SSD) in Keras | https://towardsdatascience.com/tagged/object-detection-in-keras |

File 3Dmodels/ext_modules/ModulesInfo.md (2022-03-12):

# License

`modules` is a collection of third parity 3D-print files (STL, SCAD, ...) needed to render different modules in this project.

Unless specified to the contrary, most models are licensed under the [Creative Commons - Attribution-NonCommercial-ShareAlike 4.0 International (CC BY-NC-SA 4.0)](https://creativecommons.org/licenses/by-nc-sa/4.0/) license.

# Modules

| Name | Remarks | Author | Link |
| --- | --- | --- | --- |
| `bearing.scad` | Planetary gear bearings | [Emmet Lalish](https://www.thingiverse.com/emmett/designs) | https://www.thingiverse.com/thing:53451 |
| `threads.scad` | Threads for screws and nuts<br />Original name of file: `threads-library-by-cuiso-v1.scad` | [Andres Roman Blanca](https://www.thingiverse.com/cuiso/designs) | https://www.thingiverse.com/thing:3131126 |
| `motor_mount.scad` | Original 37mm motor mount bracket.<br />The original file is not in this repository, only the modified version (`motor_mount_GM37`) | [Christopher Biggs](https://www.thingiverse.com/unixbigot/designs) | https://www.thingiverse.com/thing:2482208 |

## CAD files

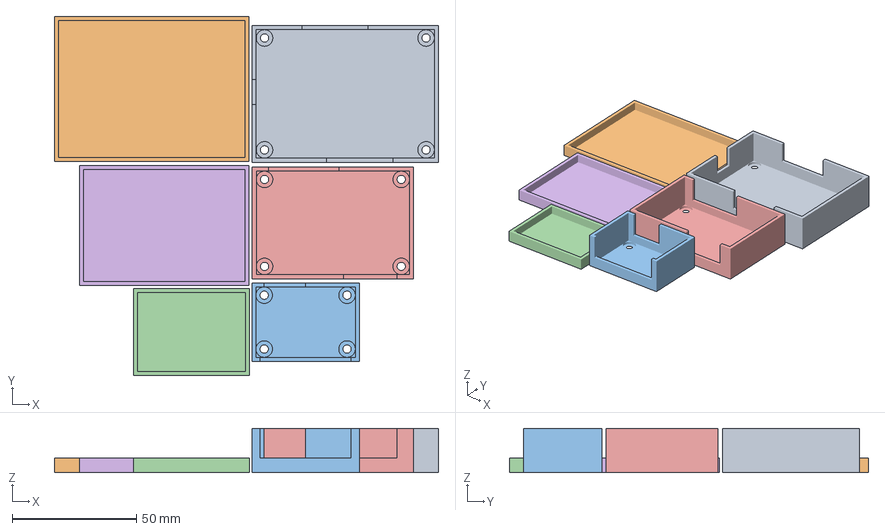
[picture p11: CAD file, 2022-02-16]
3Dmodels/enclosures/boxes.3mf
154.8 x 144.8 x 17.8 mm
pwr_supply_bottom.stl
pwr_supply_top.stl
ZK-5AD(Dual-DC-motor_ctrl)_bottom.stl
ZK-5AD(Dual-DC-motor_ctrl)_top.stl
pwr_dist_bottom.stl
pwr_dist_top.stl

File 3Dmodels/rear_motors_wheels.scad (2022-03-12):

// ----------------------------------------------------------------------------------
use<./modules/motor_mount_GM37.scad>
// ----------------------------------------------------------------------------------
module rear_motors_wheels(
  wheel_diameter=195,
  wheel_width=15,
  tread_depth=10,
  wheel_thickness=10,
  total_treads=360/15,
  spokes=360/45,
  wheels=false,
  motor=false,
  botttom_supports=false,
  draft=false,
  wall_width=2,
  tolerance=0.35
) {
  gear_length = 24;
  body_length = 57;
  motor_length = gear_length + body_length;
  color("green", alpha=0.4)
    rotate([180,0,0])
      rotate([0, 0, 90])
        difference() {
          motor_mount_GM37_simple(
            base_height=2,
            max_enclosure_length=(base_width-motor_length)/3,
            enclose_gear_only=false,
            full_enclosure=0,
            full_support=false,
            full_enclosure_wall_width=wall_width,
            render_motor=motor,
            enclosure_wall_width=4,
            tolerance=tolerance
          );
          *translate([192, 0, 0])
            cube(300, center=true);
        }
  // wheels
  if(wheels) {
    color("gray", alpha=0.25)
      translate([0, -wheel_diameter/2-tread_depth, -15.5])
        rotate([0, 90, 0])
          wheel(
            wheel_diameter = wheel_diameter - 2*tread_depth,
            wheel_width = wheel_width,
            wheel_thickness = wheel_thickness,
            
            tread_depth = tread_depth,
            tread_tickness = wheel_thickness,
            total_treads = total_treads,

            spokes = spokes,
            dshaft = true, shaft_dshaft_inset = 0,
            setscrew_nut_at_shaft = true,
            setscrew_allan_key_hole = 2.5 + tolerance,
            hub_setscrews = 1,
            draft=draft,
            tolerance = tolerance
          );
  }
}

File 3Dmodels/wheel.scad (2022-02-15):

use <../modules/bearing.scad>
use <../modules/threads.scad>

module shaft_coupling(
    coupling_length, coupling_diameter,
    shaft_diameter, dshaft_diameter, shaft_dshaft_inset,
    setscrews, setscrews_distance, setscrew_diameter, setscrew_inset, setscrew_shaft_position,
    setscrew_nut_thickness, setscrew_nut_diameter, setscrew_nut_shaft_inset, setscrew_nut_angle=0,
    as_inset=false,
    center=false
) {
  // setscrew (M3)
  setscrew_length = coupling_diameter/2;
  nut_shaft_inset = abs(setscrew_nut_shaft_inset);

  // motor D shaft
  ddshaft_diameter = (dshaft_diameter>0)?(dshaft_diameter):(shaft_diameter);
  shaft_length = coupling_length;
  dshaft_length = coupling_length - shaft_dshaft_inset;
  
  // calculate parameters
  translate_shaft_coupling = (center==true)?(shaft_length/2):(0);

  // Paint
  translate([0, 0, translate_shaft_coupling])
    difference() {
      // hub
      if(as_inset==false) {
        cylinder(d=coupling_diameter, h=coupling_length, center=true);
      }
      // shaft + setscrew
      translate([0, -shaft_diameter/2, -shaft_length/2]) {
        // setscrew
        for(screw_num = [0:setscrews-1]) {
          translate([0, ddshaft_diameter, setscrew_shaft_position + screw_num * (setscrew_nut_diameter+setscrews_distance)])
            rotate([-90, setscrew_nut_angle, 0])
              union() {
                // internal nut
                if(setscrew_nut_shaft_inset>0) {
                  translate([0, 0, -nut_shaft_inset]) {
                    cylinder(d=setscrew_nut_diameter, h=nut_shaft_inset+setscrew_nut_thickness);
                  }
                }
                else {
                  translate([0, 0, nut_shaft_inset]) {
                    cube([setscrew_nut_diameter, coupling_length, setscrew_nut_thickness], center=true);
                  }
                }
                // setscrew
                cylinder(d=setscrew_diameter, h=1.2*setscrew_length);
                if(setscrew_inset>0) {
                  translate([0, 0, setscrew_length-setscrew_inset-shaft_diameter/2])
                    cylinder(d=setscrew_nut_diameter, h=setscrew_length);
                }
              }
        }
        // motor shaft
        difference() {
          translate([0, shaft_diameter/2, -0.01])
            cylinder(d=shaft_diameter, h=0.02+shaft_length);
          // d-shaft
          if(dshaft_diameter>0) {
            translate([-dshaft_diameter, dshaft_diameter, 0])
              cube([2*dshaft_diameter, dshaft_diameter, dshaft_length]);
          }
        }
      }
    }
}

module shaft_plate_coupling(
  hub_diameter,
  setscrews, setscrew_length, setscrew_diameter, plate_setscrew_distance,
  setscrew_nut_thickness, setscrew_nut_diameter, setscrew_nut_inset, setscrew_nut_angle,
  center=false
) {
  // Paint
  center_move = (center==true) ? (-setscrew_length/2) : (0);
  nut_angle_pos = 360/setscrews;
  translate([0 , 0 , center_move])
    for(screw_num = [0:setscrews-1]) {
      rotate([0, 0, screw_num*nut_angle_pos])
        translate([plate_setscrew_distance, 0, 0])
          union() {
            // internal nut
            translate([0, 0, setscrew_length - setscrew_nut_thickness - setscrew_nut_inset]) {
              // nut
              rotate([0, 0, setscrew_nut_angle])
                cylinder(d=setscrew_nut_diameter, h=setscrew_nut_thickness, $fn=6);
              // nut slot
              translate([0, -setscrew_nut_diameter/2, 0])
                cube([hub_diameter/2, setscrew_nut_diameter, setscrew_nut_thickness]);
            }
            // setscrew
            cylinder(d=setscrew_diameter, h=setscrew_length);
          }
    }
}

module wheel(
  wheel_diameter, wheel_width, wheel_thickness,
  tread_depth, tread_tickness, total_treads,
  spokes,
  motor_coupling = true,
  motor_plate_coupling = false,
  add_bearing = false,
  screw_wheel = false,
  dshaft = true, shaft_dshaft_inset = 0,
  hub_setscrews = 2,
  setscrew_nut_at_shaft=true,
  setscrew_allan_key_hole = 0,
  hub_diameter = 0,
  hub_support_diameter = 0,
  draft=false,
  tolerance = 0.5
)
{
  // Design parameters
  
  $fn=100;

  rim_width = wheel_width;
  rim_thickness = tread_tickness;
  
  hub_height = (motor_coupling)?(wheel_width):(wheel_width);
  hub_support_diameter_set = (add_bearing)?(60):( (hub_support_diameter)?(hub_support_diameter):(30));
  hub_diameter_d = (add_bearing)?(70):(23);
  hub_diameter_inset = (hub_diameter)?(hub_diameter):(20 + tolerance);
  hub_setscrews_distance = (setscrew_nut_at_shaft)?(0):(0.6);
  hub_setscrew_diameter = 3 + tolerance;
  hub_setscrew_inset = (dshaft==true)?(1):(1.8);
  hub_shaft_diameter = 6 + tolerance;
  hub_dshaft_diameter = (dshaft==true)?(5.4 + tolerance):(0);
  hub_shaft_dshaft_inset = (dshaft==true)?(shaft_dshaft_inset):(0);
  hub_setscrew_nut_diameter = (setscrew_nut_at_shaft)?(6.5 + tolerance):(5.5 + tolerance);
  hub_setscrew_nut_thickness = 2.3 + tolerance;
  hub_setscrew_nut_shaft_inset = (setscrew_nut_at_shaft)?(hub_shaft_diameter/2):(-3.5);
  motor_shaft_length = 12;
  hub_setscrew_height = (hub_height - hub_shaft_dshaft_inset) - hub_setscrews*motor_shaft_length/(1+hub_setscrews) - hub_setscrews_distance;

  plate_thickness = 2;
  plate_setscrew_nut_diameter = 6 + tolerance;
  plate_setscrew_length = 8 + tolerance;
  plate_setscrew_distance = 8;
  plate_setscrew_diameter = 3 + tolerance;
  plate_setscrew_nut_thickness = 2.5 + tolerance;
    
  // Calculate parameters
  tread_angle = (total_treads>0)?(360/total_treads):(0);
  rim_angle = 360/spokes;
  
  // Paint
  difference() {
    union() {
      difference() {
        translate([0, 0, wheel_width/2]) {
          // Exterior Wheel
          difference() {
            cylinder(d=wheel_diameter, h=wheel_width, center=true);
            cylinder(d=wheel_diameter-2*wheel_thickness, h=3*wheel_width, center=true);
          }
          // treads
          if(draft==false) {
            offset = 2;
            if(tread_angle) {
              for(ang=[0:tread_angle:360])
              {
                rotate([0, 0, ang])
                  translate([wheel_diameter/2, 0, 0])
                    difference()
                    {
                      translate([-offset, 0, -wheel_width/2])
                        linear_extrude(height=wheel_width)
                          polygon(points=[ [0, tread_tickness/2 + offset/2], [0, -tread_tickness/2 - offset/2], [tread_tickness/2 + tread_depth + offset, 0] ]);
                      translate([1.5*tread_depth, 0, 0])
                        cube([tread_depth, tread_tickness, 1.2*wheel_width], center=true);
                      //translate([tread_depth/2, 0, 0]) cube([tread_depth, tread_tickness, 1.2*wheel_width], center=true);
                    }
              }
            }
            
            // Rim
            translate([0,0, rim_width/2 - wheel_width/2])
              for(ang=[0:rim_angle:360]) {
                rotate([0, 0, ang])
                  cube([wheel_diameter-wheel_width/4, rim_thickness, rim_width], center=true);
              }
            
            // Hub support
            cylinder(d=hub_support_diameter_set, h=hub_height, center=true);
          }
          else {
            // Rim
            translate([0,0, rim_width/2 - wheel_width/2])
              for(ang=[0:rim_angle:360]) {
                rotate([0, 0, ang])
                  cube([wheel_diameter-wheel_width/4+2*tread_depth, rim_thickness, rim_width], center=true);
              }
          }
        }
        if(draft==false) {
          // Get hub space
          if(motor_coupling || add_bearing) {
            translate([0, 0, hub_height/2])
              cylinder(d=hub_diameter_d-tolerance, h=1.2*hub_height, center=true);
          }
          else {
            if(screw_wheel) {
              translate([0, 0, -wheel_width])
                thread_for_nut(diameter=hub_diameter, length=3*wheel_width);
            }
            else {
              translate([0, 0, hub_height/2])
                cylinder(d=hub_diameter_inset, h=1.2*hub_height, center=true);
            }
          }
        }
      }

      // Motor coupling
      if(motor_coupling) {
        union() {
          rotate([0, 0, rim_angle/2-90])
            shaft_coupling(
              coupling_length=hub_height, coupling_diameter=hub_diameter_d,
              shaft_diameter=hub_shaft_diameter, dshaft_diameter=hub_dshaft_diameter, shaft_dshaft_inset=hub_shaft_dshaft_inset,
              setscrews=hub_setscrews, setscrews_distance=hub_setscrews_distance, setscrew_diameter=hub_setscrew_diameter, setscrew_inset=hub_setscrew_inset, setscrew_shaft_position=hub_setscrew_height,
              setscrew_nut_thickness=hub_setscrew_nut_thickness, setscrew_nut_diameter=hub_setscrew_nut_diameter, setscrew_nut_shaft_inset=hub_setscrew_nut_shaft_inset, setscrew_nut_angle=0,
              center=true);
        }
      }
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

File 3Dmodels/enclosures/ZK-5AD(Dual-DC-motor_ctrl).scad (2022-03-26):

// ----------------------------------------------------------------------------------
// Print settings:
// - Infill: 15% (or less if bridges OK)
// ----------------------------------------------------------------------------------
include<../modules/printer_limits.scad>
use<../modules/enclosure_box.scad>
// ----------------------------------------------------------------------------------
// DIMENSIONS
zk5ad_wall_width = ptr_wall_width;
zk5ad_bottom_wall_width = z_dim_adj(2);

zk5ad_screws_hide_offset = z_dim_adj(xy_screw_3mm_hd_h + 3);

zk5ad_l = 39;
zk5ad_w = 28.5;
zk5ad_h = z_dim_adj(22 + zk5ad_screws_hide_offset) ;
zk5ad_board_bt_clearence = z_dim_adj(4 + zk5ad_screws_hide_offset);
zk5ad_lid_h = z_dim_adj(6);

// ------------------------------------------
// Screws
zk5ad_screws_xy = [
  [            3*zk5ad_wall_width, 3*zk5ad_wall_width],
  [zk5ad_l - 1*zk5ad_wall_width, 3*zk5ad_wall_width],
  [            3*zk5ad_wall_width, zk5ad_w-1*zk5ad_wall_width],
  [zk5ad_l - 1*zk5ad_wall_width, zk5ad_w-1*zk5ad_wall_width]
];

module zk5ad_enclosure(
  fitted_lid=true,
  draw_lid=false,
  draw_container=false,
  draw_as_close_box=false
)
{
  echo("----------------------------------------------------------------------------------------------------------------------------------------------------");
  echo("ZK-5AD Dual DC-motor H-Bridge Enclosure");
  if(draw_container || draw_as_close_box ) {
    difference() {
      enclosure_box(
        length=zk5ad_l, width=zk5ad_w, height=zk5ad_h, lid_height=zk5ad_lid_h,
        xy_wall_width=zk5ad_wall_width, z_wall_width=zk5ad_bottom_wall_width,
        fitted_lid=fitted_lid, draw_container=true,
        xy_screws=[xy_screw_3mm_d, zk5ad_screws_xy],
        xy_screws_hide=[xy_screw_3mm_hd_d, zk5ad_screws_hide_offset],
        tolerance=ptr_tolerance
      );
      translate([1+zk5ad_wall_width, -zk5ad_wall_width, zk5ad_bottom_wall_width+zk5ad_board_bt_clearence])
        cube([36, 3*zk5ad_wall_width, zk5ad_h+zk5ad_bottom_wall_width]);
    }
  }
  if(draw_lid || draw_as_close_box) {
    rotate(enclosure_close_box_lid_rotate_ang(draw_as_close_box))
      translate(enclosure_close_box_lid_translate_xyz(draw_as_close_box=draw_as_close_box, length=zk5ad_l, width=zk5ad_w, height=zk5ad_h, xy_wall_width=zk5ad_wall_width, z_wall_width=zk5ad_bottom_wall_width))
        difference() {
          enclosure_box(
            length=zk5ad_l, width=zk5ad_w, height=zk5ad_h, lid_height=zk5ad_lid_h,
            xy_wall_width=zk5ad_wall_width, z_wall_width=zk5ad_bottom_wall_width,
            fitted_lid=fitted_lid, draw_lid=true,
            tolerance=ptr_tolerance
          );
          // IO socket
          //translate([2*zk5ad_wall_width, 1*zk5ad_wall_width-0.01, -2*zk5ad_bottom_wall_width])
          translate([zk5ad_l+0*zk5ad_wall_width-16, zk5ad_w-2*zk5ad_wall_width+0.01, -2*zk5ad_bottom_wall_width])
            cube([16, 3*zk5ad_wall_width+0.01, zk5ad_h+zk5ad_bottom_wall_width]);
        }
      }
}

*difference() {
  *zk5ad_enclosure(draw_as_close_box=true);
  *zk5ad_enclosure(draw_lid=true, draw_container=true);
  zk5ad_enclosure(draw_container=true);
  *translate([zk5ad_enclosure_l/2, -10, -10])
    cube(500);
}

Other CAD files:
3Dmodels/modules/motor_mount_GM37.scad
3Dmodels/enclosures/HBV-1780-2.stereocam.scad
3Dmodels/enclosures/kv260_enclosure.scad
3Dmodels/enclosures/pwr_dist.scad
3Dmodels/enclosures/pwr_supply.scad
3Dmodels/enclosures/ttgo-t1-case.scad
3Dmodels/ext_modules/bearing.scad
3Dmodels/ext_modules/o_ring.scad
3Dmodels/ext_modules/threads.scad
3Dmodels/kv260_atrover_mini.scad
3Dmodels/kv260_atrover_mini_dims.scad
3Dmodels/modules/caster.scad
3Dmodels/modules/caster_bearing.scad
3Dmodels/modules/enclosure_box.scad
3Dmodels/modules/holding_screws.scad
3Dmodels/modules/printer_limits.scad
3Dmodels/modules/wheel.scad

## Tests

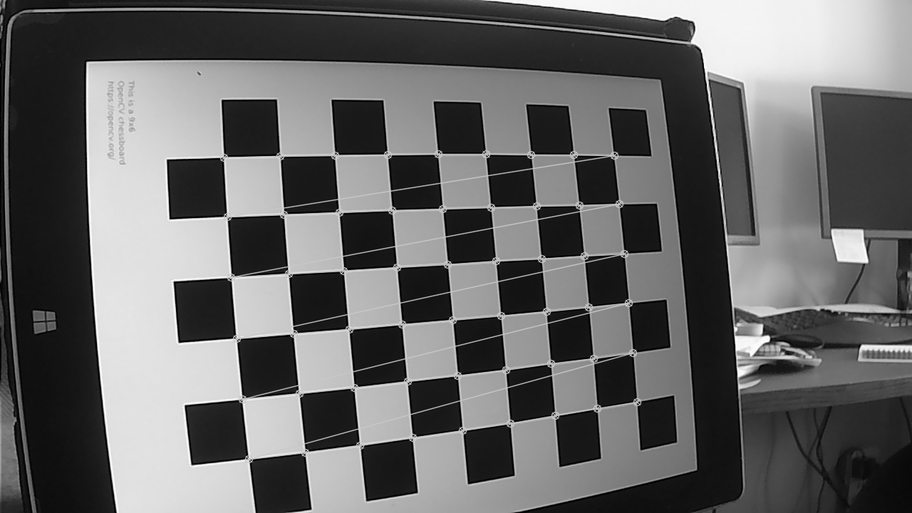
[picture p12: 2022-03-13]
scripts/camera_calibration_data_gen/images/calibration/w2560_h720/rgt_5.png

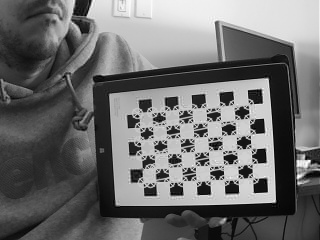
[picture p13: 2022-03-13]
scripts/camera_calibration_data_gen/images/calibration/w640_h240/lft_4.png

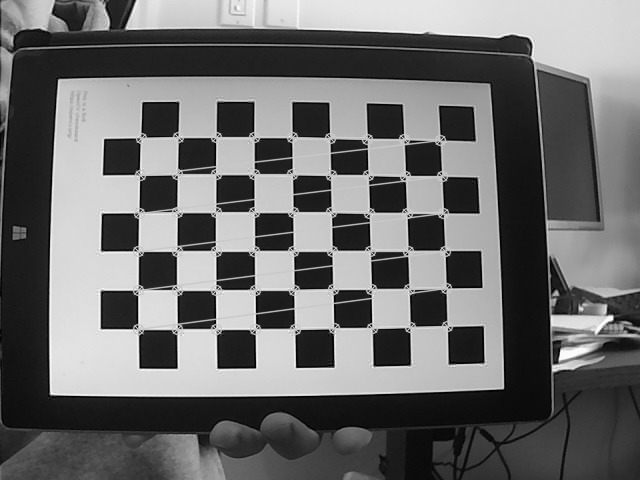
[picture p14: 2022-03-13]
scripts/camera_calibration_data_gen/images/calibration/w1280_h480/rgt_3.png

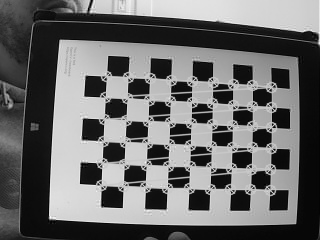
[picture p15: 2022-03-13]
scripts/camera_calibration_data_gen/images/calibration/w640_h240/lft_0.png

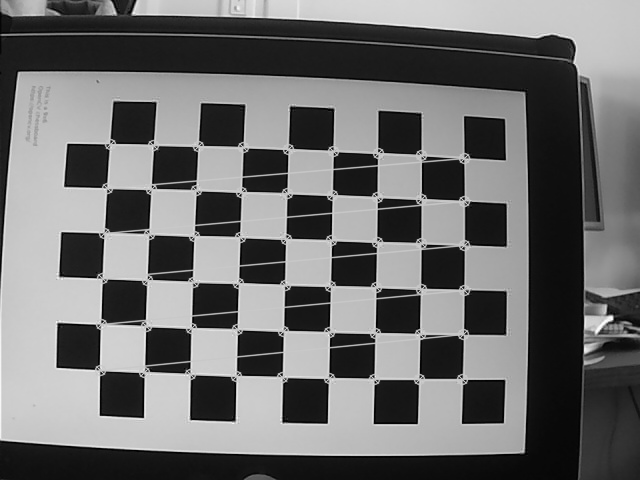
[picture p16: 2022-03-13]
scripts/camera_calibration_data_gen/images/calibration/w1280_h480/rgt_0.png

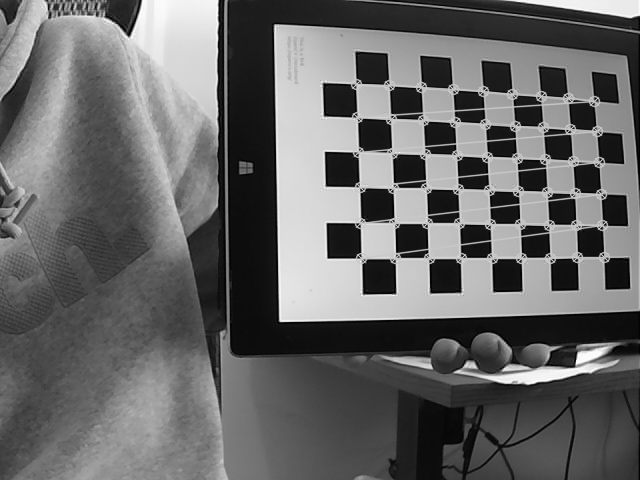
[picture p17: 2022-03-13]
scripts/camera_calibration_data_gen/images/calibration/w1280_h480/lft_6.png

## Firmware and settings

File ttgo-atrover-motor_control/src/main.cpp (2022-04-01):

// ------------------------------------------------------------------------
// TTGO-T1
// - ATROVER DC motors control (via UART)
//
// Serial protocol
// !###: Emergency stop
// *: commands (speed = atoi(###))
//    f###: move forward
//    b###: move backward atoi(###)
//    l###: turn left atoi(###)
//    r###: turn right atoi(###)
//    s000: stop
//
// B: busy
// I: idle
// I###: ACK idle
// ------------------------------------------------------------------------
#include <Arduino.h>
#include <stdlib.h>
#include "ttgo-t1-setup.h"
// ------------------------------------------------------------------------
#include "gui.h"
// refresh_rate=1000ms, wlcm_msg
clGUI GUI(1000, static_cast<const char*>("K-ATR Motor Ctrl"));
// ------------------------------------------------------------------------
#include "dc_motors_pwm.h"
// PWMFreq=5000, PWMResolution=8, min_speed=32, max_speed=0, speed_step=8, accel_step_ms=1
// max_speed == 0 -> set max available
clDualDC_MotorCtrl DualDC_MotorCtrl(8, 8, 48, 128, 8, 400);
// ------------------------------------------------------------------------
void setup(void) {
  buttons_init(buttons_hndlr);
  GUI.init();
  DualDC_MotorCtrl.init();
  
  Serial.begin(115200);
  Serial.print("?TTGO");
}
// ------------------------------------------------------------------------
bool report_idle = false;
void loop() {
  loop_buttons();
  GUI.loop();
  if(DualDC_MotorCtrl.loop()) {
    if(report_idle==true) {
      Serial.print('I');
    }
  }
  
  if(Serial.available()>4)
  {
    uint8_t buff[5];
    static_cast<void>( Serial.read(buff, 5) );
    
    // ACK received command by echo
    Serial.write(buff, 5);
    
    // Emergency stop
    if(buff[0]=='!') {
      DualDC_MotorCtrl.emergency_stop();
    }
    // ACK IDLE
    else if(buff[0]=='I') {
      report_idle = false;
    }
    // New movement request
    else if(buff[0]=='*') {
      report_idle = true;
      auto speed = atoi(reinterpret_cast<char*>(&buff[2]));
      switch(buff[1]) {
        case 'f': {
          DualDC_MotorCtrl.move_forward(speed);
          break;
        }
        case 'b': {
          DualDC_MotorCtrl.move_backward(speed);
          break;
        }
        case 'l': {
          DualDC_MotorCtrl.turn_left(speed);
          break;
        }
        case 'r': {
          DualDC_MotorCtrl.turn_right(speed);
          break;
        }
        default: {
          DualDC_MotorCtrl.stop();
          break;
        }
      }
    }
  }
}
// ------------------------------------------------------------------------

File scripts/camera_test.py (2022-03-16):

import numpy as np
import pandas as pd
import cv2
import random as rnd
from pprint import pprint

def drawText(frame, txt, location, color = (128,128,128)):
    cv2.putText(frame, txt, location, cv2.FONT_HERSHEY_PLAIN, 1, color, 1, cv2.LINE_4)
    
def print_webcam_resolutions(cam):
    #https://www.learnpythonwithrune.org/find-all-possible-webcam-resolutions-with-opencv-in-python/
    url = "https://en.wikipedia.org/wiki/List_of_common_resolutions"
    table = pd.read_html(url)[0]
    table.columns = table.columns.droplevel()
    resolutions = {}
    
    for index, row in table[["W", "H"]].iterrows():
        cam.set(cv2.CAP_PROP_FRAME_WIDTH, row["W"])
        cam.set(cv2.CAP_PROP_FRAME_HEIGHT, row["H"])
        width = cam.get(cv2.CAP_PROP_FRAME_WIDTH)
        height = cam.get(cv2.CAP_PROP_FRAME_HEIGHT)
        resolutions[str(width)+" x "+str(height)] = "OK"
    
    print(f"Webcam resolutions (WxH)): {resolutions}")

def get_fps(cam, num_frames=100):
    tick_cnt_start = cv2.getTickCount()
    for _ in range(0, num_frames):
        ret, frame = cam.read()
        
    elapsed = (cv2.getTickCount() - tick_cnt_start) / cv2.getTickFrequency()
    return num_frames/elapsed

def get_cam_params(cam):
    cam_params = {
        "width": cam.get(cv2.CAP_PROP_FRAME_WIDTH),
        "height": cam.get(cv2.CAP_PROP_FRAME_HEIGHT),
        "fps": cam.get(cv2.CAP_PROP_FPS),
        "bright": cam.get(cv2.CAP_PROP_BRIGHTNESS),
        "contr": cam.get(cv2.CAP_PROP_CONTRAST ),
        "sat": cam.get(cv2.CAP_PROP_SATURATION ),
        "hue": cam.get(cv2.CAP_PROP_HUE),
        "gain": cam.get(cv2.CAP_PROP_GAIN),
        "exposure ": cam.get(cv2.CAP_PROP_EXPOSURE ),
        "ch": cam.get(cv2.CAP_PROP_CHANNEL),
        "auto-wb": cam.get(cv2.CAP_PROP_AUTO_WB ),
        "wb-temp": cam.get(cv2.CAP_PROP_WB_TEMPERATURE ),
        "bitrate": cam.get(cv2.CAP_PROP_BITRATE),
    }
    return {nm:vl for nm, vl in cam_params.items() if vl>=0}
    
cam = cv2.VideoCapture(0)
if not cam.isOpened():
    print("Cannot open camera")
    exit()
    
# Setup camera
#pprint(get_cam_params(cam))
#print(f"Measured fps: {get_fps(cam)}")

# Select resolution
#print_webcam_resolutions(cam)

#cam.set(cv2.CAP_PROP_FRAME_WIDTH, 640)
#cam.set(cv2.CAP_PROP_FRAME_HEIGHT, 240)
cam.set(cv2.CAP_PROP_FRAME_WIDTH, 1280)
frame_width = 1280
cam.set(cv2.CAP_PROP_FRAME_HEIGHT, 480)
frame_heigth = 480
#cam.set(cv2.CAP_PROP_FRAME_WIDTH, 2560)
#cam.set(cv2.CAP_PROP_FRAME_HEIGHT, 720)
#pprint(get_cam_params(cam))
#fps = get_fps(cam)
#print(f"Measured fps: {fps}")
fps = cam.get(cv2.CAP_PROP_FPS)

num_frames = 0
avg_frames = 10
tick_cnt_start = cv2.getTickCount()
while True:
    # Capture frame-by-frame
    ret, frame = cam.read()
    #frame, rgt_frame = frame[:, :frame_width//2], frame[:, frame_width//2:]
    
    img_out = frame.copy()
    num_frames += 1
    
    # if frame is read correctly ret is True
    if not ret:
        print("Can't receive frame (stream end?). Exiting ...")
        break
    
    # Show original
    cv2.imshow('original', frame)
    proc_txt = []
    
    # flip
    #flipped = cv2.flip(frame, 0)
    
    # gray -> blur -> canny
    frame = cv2.cvtColor(frame, cv2.COLOR_BGR2GRAY)
    #proc_txt.append("COLOR_BGR2GRAY")
    frame = cv2.GaussianBlur(frame, (5, 5), 0)
    #proc_txt.append("GaussianBlur(5x5)")
    frame = cv2.Canny(frame, 30, 150)
    #proc_txt.append("Canny(30->150)")
    
    # dilation
    dilation_value = 3
    dilation_iterations = 2
    dilation_kernel = np.ones((dilation_value,dilation_value),np.uint8)
    #frame = cv2.dilate(frame, dilation_kernel, iterations=dilation_iterations)
    
    # show transformations
    cv2.imshow('filtered', frame)
    
    # Countours
    contours, hierarchy = cv2.findContours(frame, cv2.RETR_EXTERNAL, cv2.CHAIN_APPROX_SIMPLE)
    proc_txt.append(f"contours#: {len(contours)}")
    
    # Generate output
    cv2.drawContours(img_out, contours, -1, (250,250,250), 1)
    #for i in range(len(contours)):
    #    color = (rnd.randint(0,256), rnd.randint(0,256), rnd.randint(0,256))
    #    cv2.drawContours(img_out, contours, i, color, 2, cv2.LINE_8, hierarchy, 0)
    
    # Draw info
    drawText(img_out, f"[{('| ').join(proc_txt)}]", (20,20))
    
    # Calculate Frames per second (FPS)
    if num_frames == avg_frames:
        elapsed = (cv2.getTickCount() - tick_cnt_start) / cv2.getTickFrequency()
        fps = num_frames/elapsed
        
        tick_cnt_start = cv2.getTickCount()
        num_frames = 0
    
    drawText(img_out, f"FPS: {fps:.2f}", (20,50))
    
    # Draw final
    cv2.imshow("Countours", img_out)
    
    if cv2.waitKey(1) == ord('q'):
        break
    
# When everything done, release the capture
cam.release()
cv2.destroyAllWindows()

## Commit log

2022-02-15 Added modules boxes
    [ZK-5AD(Dual-DC-motor_ctrl).scad, ZK-5AD(Dual-DC-motor_ctrl).stl, bearing.scad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]
2022-02-16 boxes adjust
    [ZK-5AD(Dual-DC-motor_ctrl).stl, ZK-5AD(Dual-DC-motor_ctrl)_bottom.stl, ZK-5AD(Dual-DC-motor_ctrl)_top.stl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]
2022-02-16 first kv-260 enclosure draft
    [boxes.3mf, kv260-enclosure.3mf, kv260_enclosure.scad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]
2022-02-20 kv260 enclosure + stereo cam enclosure (draft)
    [HBV-1780-2.stereocam.scad, HBV-1780-2.stereocam.stl, kv260-enclosure.3mf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]
2022-02-20 kv260 and stereo cam (draft) enclosures
    [HBV-1780-2.stereocam.scad, kv260_enclosure.scad]
2022-02-20 renamed top 3D block
    [kv260_atrover_mini.scad, mini_atrover.scad]
2022-02-23 stereo cam case, kv260 case, licenses updates
    [HBV-1780-2.stereocam.scad, HBV-1780-2.stereocam.stl, kv260_atrover_mini_dims.scad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]
2022-02-23 Added motors, wheels, caster modules. Updated mini model with new blocks
    [HBV-1780-2.stereocam.scad, HBV-1780-2.stereocam.stl, ZK-5AD(Dual-DC-motor_ctrl).scad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]
2022-02-26 kv260 to module + screws adjust
    [kv260_enclosure.scad]
2022-02-26 moved bearings.scda to proper directory
    [bearing.scad]
2022-02-26 added printer_limits to 3d models
    [printer_limits.scad]
2022-02-26 top 3d + battery + screws (kv260_enclosure), split rear_motor_wheels.scad
    [kv260_atrover_mini.scad, kv260_atrover_mini_dims.scad, rear_motors_wheels.scad]
2022-02-27 Updated printer limits to #wall_lines - from prusaslicer
    [printer_limits.scad]
2022-02-27 3Dprint: kv260_mini added draft/test options
    [kv260_atrover_mini.scad]
2022-02-27 3D model: kv260_enclosure screws adjust to match top lvl
    [kv260_enclosure.scad]
2022-02-27 3Dprint: motors_base adjust
    [printer_limits.scad, rear_motors_wheels.scad]
2022-02-27 sync LF/NL chars
    [HBV-1780-2.stereocam.scad, ZK-5AD(Dual-DC-motor_ctrl).scad, caster.scad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]
2022-03-01 3D models top & kv260 updates
    [kv260_atrover_mini.scad, kv260_enclosure.scad, motor_mount_GM37.scad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]
2022-03-02 more 3D updates
    [enclosure_box.scad, kv260_enclosure.scad, printer_limits.scad]
2022-03-03 3D models: removed unsued files, cleanup and tune-up
    [enclosure_box.scad, kv260_atrover_mini.scad, kv260_enclosure.scad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]
2022-03-03 3D models: fix commented wrong lines
    [kv260_enclosure.scad]
2022-03-03 3Dmodels: stereocam redo, kv260 minor adjustments
    [HBV-1780-2.stereocam.scad, HBV-1780-2.stereocam.stl, kv260_enclosure.scad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]
2022-03-04 3d models: stereo cam dims adjust
    [HBV-1780-2.stereocam.scad, HBV-1780-2.stereocam.stl, enclosure_box.scad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]
2022-03-05 3d-models: ZK-5AD to new format
    [HBV-1780-2.stereocam.scad, ZK-5AD(Dual-DC-motor_ctrl).scad, ZK-5AD(Dual-DC-motor_ctrl).stl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]
2022-03-05 3d models fine adjustments
    [HBV-1780-2.stereocam.scad, ZK-5AD(Dual-DC-motor_ctrl).scad, kv260_enclosure.scad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]
2022-03-06 3d models: added option of not using 3d print casters
    [caster.scad, caster_bearing.scad, kv260_atrover_mini.scad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]
2022-03-06 3d models: caster adjust
    [kv260_atrover_mini.scad, kv260_atrover_mini_caster_test.stl, printer_limits.scad]
2022-03-08 3d models: bat enclosure adjust.
    [kv260_atrover_bat_slide_test.stl, kv260_atrover_bat_slot_test.stl, kv260_atrover_mini.scad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]
2022-03-08 3d models: bat enclosure tunning
    [kv260_atrover_bat_slide_test.stl, kv260_atrover_bat_slot_test.stl, kv260_atrover_mini.scad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]
2022-03-09 3d models pwr_dist tuning
    [kv260_atrover_mini_dims.scad, pwr_dist.scad, pwr_dist.stl]
2022-03-09 3d models: fixed kv260_enclosure orientation
    [kv260_atrover_mini.scad, kv260_atrover_mini.stl, kv260_enclosure.scad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]
2022-03-10 3d models: first draft completed, added notes to improve models later
    [kv260_atrover_mini.scad, kv260_atrover_mini_bat_cover.stl, pwr_dist.scad]
2022-03-11 3D models: fixed kv260 enclosure PMOD... slots
    [kv260_enclosure.scad, kv260_enclosure_bottom.stl, printer_limits.scad]
2022-03-12 3D models: rotated battery position and pwr dist box. Added nuts for casters. Removed stl files
    [HBV-1780-2.stereocam.stl, ZK-5AD(Dual-DC-motor_ctrl).stl, ZK-5AD(Dual-DC-motor_ctrl)_bottom.stl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]
2022-03-12 stereo camera calibration scripts + results (1280x480)
2022-03-13 scripts: move calibration results to new folder
2022-03-13 updated camera calibration values
2022-03-15 minor 3dmodels updates
    [kv260_enclosure.scad]
2022-03-25 3D models: adjust for ZK-5AD motor pwr/drv enclosure
    [ZK-5AD(Dual-DC-motor_ctrl).scad, enclosure_box.scad, kv260_enclosure.scad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]
2022-03-25 Updated 3D models. ttgo board enclosure, zk-motor_drv update for screws
    [ZK-5AD(Dual-DC-motor_ctrl).scad, enclosure_box.scad, kv260_enclosure.scad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]
2022-03-26 ttgo FW for motor control via UART
2022-03-26 ttgo motor control: minor GUI update
2022-03-27 camera_test image
2022-03-30 added base KRIA->TTGO motor test
2022-03-31 adjusted motor speeds on carpet
2022-04-01 fix on TTGO response
    [main.cpp]
2022-04-01 Adding missing files before tag
    [dpu_yolov4.py, dpu_yolov4_test.py]
